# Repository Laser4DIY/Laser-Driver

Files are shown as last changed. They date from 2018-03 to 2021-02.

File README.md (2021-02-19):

# LASER4DIY Laser Diode Driver

Constant current power supply for laser diode to be used for the Laser4DIY project, see http://www.laser4diy.org/

Note: we are currently developing a new improved version of the laser diode driver, see https://github.com/Laser4DIY/Laser-Driver-v2

Copyright FabLab München e.V.  2021.

This source describes Open Hardware and is licensed under the CERN-OHL-P v2

You may redistribute and modify this documentation and make products using it 
under the terms of the CERN-OHL-P v2 (https:/cern.ch/cern-ohl).
This documentation is distributed WITHOUT ANY EXPRESS OR IMPLIED WARRANTY, 
INCLUDING OF MERCHANTABILITY, SATISFACTORY QUALITY AND FITNESS FOR A  PARTICULAR 
PURPOSE. Please see the CERN-OHL-P v2 for applicable conditions

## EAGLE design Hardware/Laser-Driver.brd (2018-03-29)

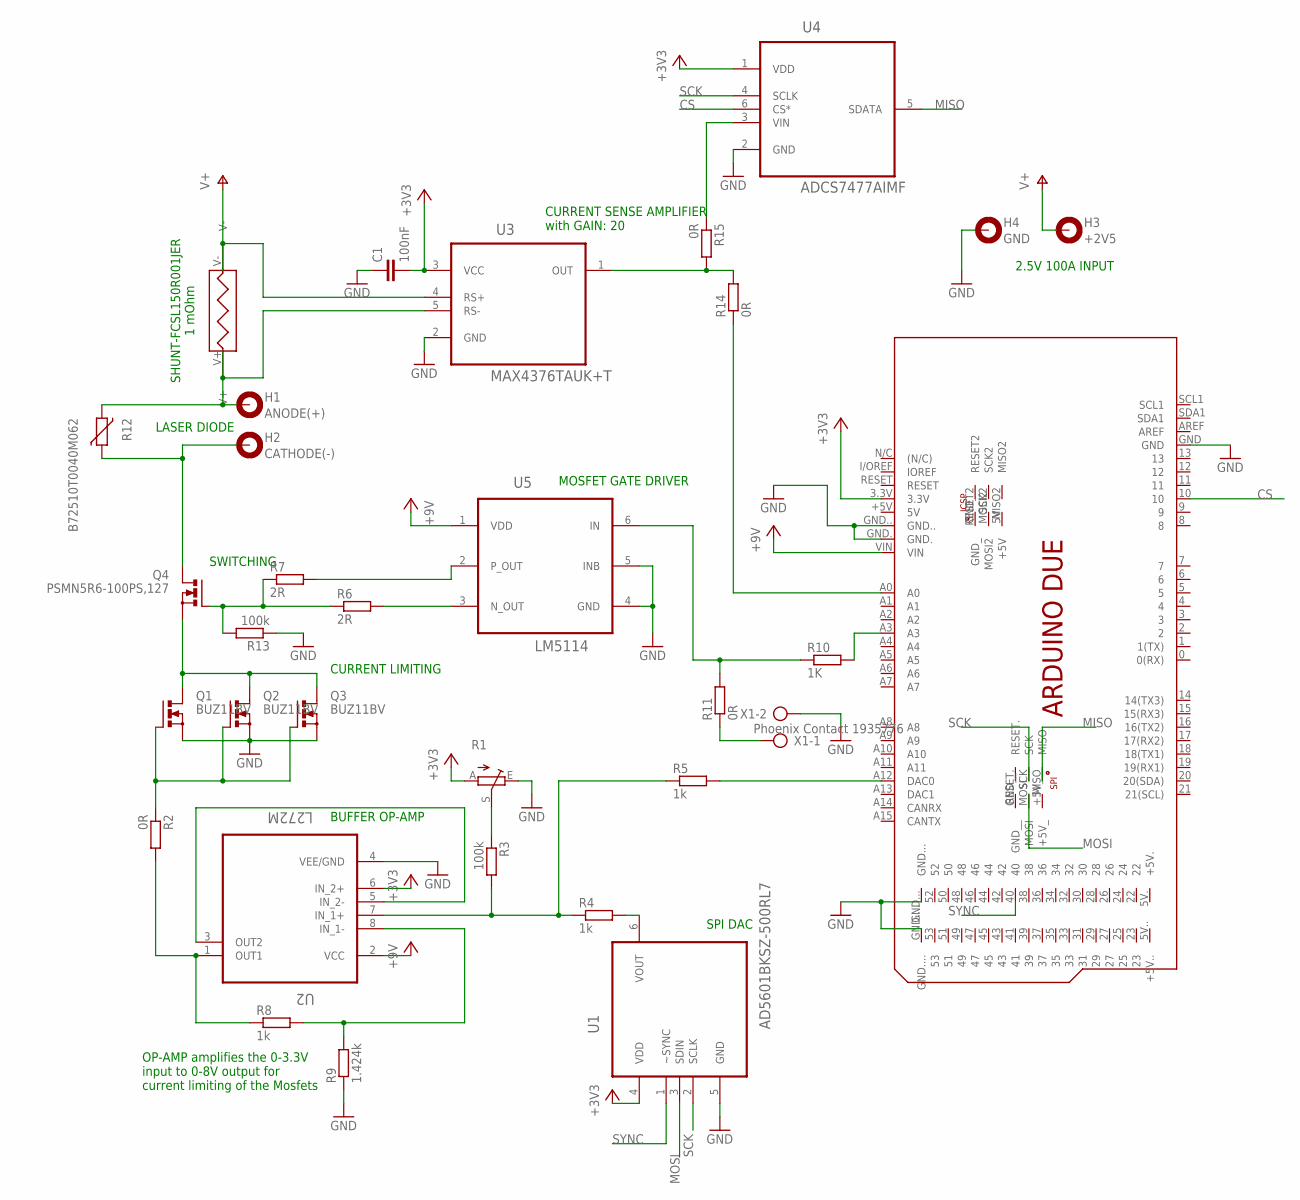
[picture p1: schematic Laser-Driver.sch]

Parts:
C1: 100nF; C0805
H1: ANODE(+); 3,2-PAD
H2: CATHODE(-); 3,2-PAD
H3: +2V5; 3,2-PAD
H4: GND; 3,2-PAD
PCB1: ARDUINO_DUE_SHIELD_SPI
Q1, Q2, Q3: BUZ11BV; TO220BV
Q4: PSMN5R6-100PS,127; TO220BV
R1: TRIM_EU-B64W; B64W
R2, R11, R14, R15: 0R; R0805
R3, R13: 100k; R0805
R4, R5, R8: 1k; R0805
R6, R7: 2R; R0805
R9: 1.424k; R0805
R10: 1K; R0805
R12: B72510T0040M062; CT/CN0805
U1: AD5601BKSZ-500RL7; SOT65P210X110-6N
U2: L272M; DIP254P762X508-8
U3: MAX4376TAUK+T; SOT95P280X145-5N
U4: ADCS7477AIMF; SOT95P280X145-6N
U5: LM5114; SOT95P280X145-6N
U$1: SHUNT-FCSL150R001-NOKELVIN
X1: Phoenix Contact 1935776; AK500/2

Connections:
+2V5: H3.B3,2, U3.4 (RS+), U$1.V-
+3V3: C1.2, PCB1.3.3V, R1.A, U1.4 (VDD), U2.6 (IN_2+), U3.3 (VCC), U4.1 (VDD)
+9V: PCB1.VIN, U2.2 (VCC), U5.1 (VDD)
CS: PCB1.10, U4.6 (CS*)
GND: C1.1, H4.B3,2, PCB1.GND, PCB1.GND., PCB1.GND.., PCB1.GND..., PCB1.GND...., Q1.S, Q2.S, Q3.S, R1.E, R9.1, R13.1, U1.5 (GND), U2.4 (VEE/GND), U3.2 (GND), U4.2 (GND), U5.4 (GND), U5.5 (INB), X1.2
MISO: PCB1.MISO, U4.5 (SDATA)
MOSI: PCB1.MOSI, U1.3 (SDIN)
unnamed: R7.2, U5.2 (P_OUT)
unnamed: H1.B3,2, R12.2, U3.5 (RS-), U$1.V+
unnamed: Q1.D, Q2.D, Q3.D, Q4.S
unnamed: R6.2, U5.3 (N_OUT)
unnamed: R2.2, R8.1, U2.1 (OUT1)
unnamed: Q1.G, Q2.G, Q3.G, R2.1
unnamed: U2.3 (OUT2), U2.5 (IN_2-)
unnamed: R3.2, R4.1, R5.1, U2.7 (IN_1+)
unnamed: R1.S, R3.1
unnamed: R4.2, U1.6 (VOUT)
unnamed: PCB1.A12 (DAC0), R5.2
unnamed: PCB1.A0, R14.1
unnamed: R8.2, R9.2, U2.8 (IN_1-)
unnamed: R10.1, R11.2, U5.6 (IN)
unnamed: PCB1.A3, R10.2
unnamed: R11.1, X1.1
unnamed: Q4.G, R6.1, R7.1, R13.2
unnamed: R14.2, R15.2, U3.1 (OUT)
unnamed: H2.B3,2, Q4.D, R12.1
unnamed: R15.1, U4.3 (VIN)
SCK: PCB1.SCK, U1.2 (SCLK), U4.4 (SCLK)
SYNC: PCB1.40, U1.1 (~SYNC)

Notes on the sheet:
SHUNT-FCSL150R001JER 1 mOhm
CURRENT SENSE AMPLIFIER with GAIN: 20
MOSFET GATE DRIVER
BUFFER OP-AMP
SPI DAC
LASER DIODE
2.5V 100A INPUT
OP-AMP amplifies the 0-3.3V input to 0-8V output for current limiting of the Mosfets
SWITCHING
CURRENT LIMITING

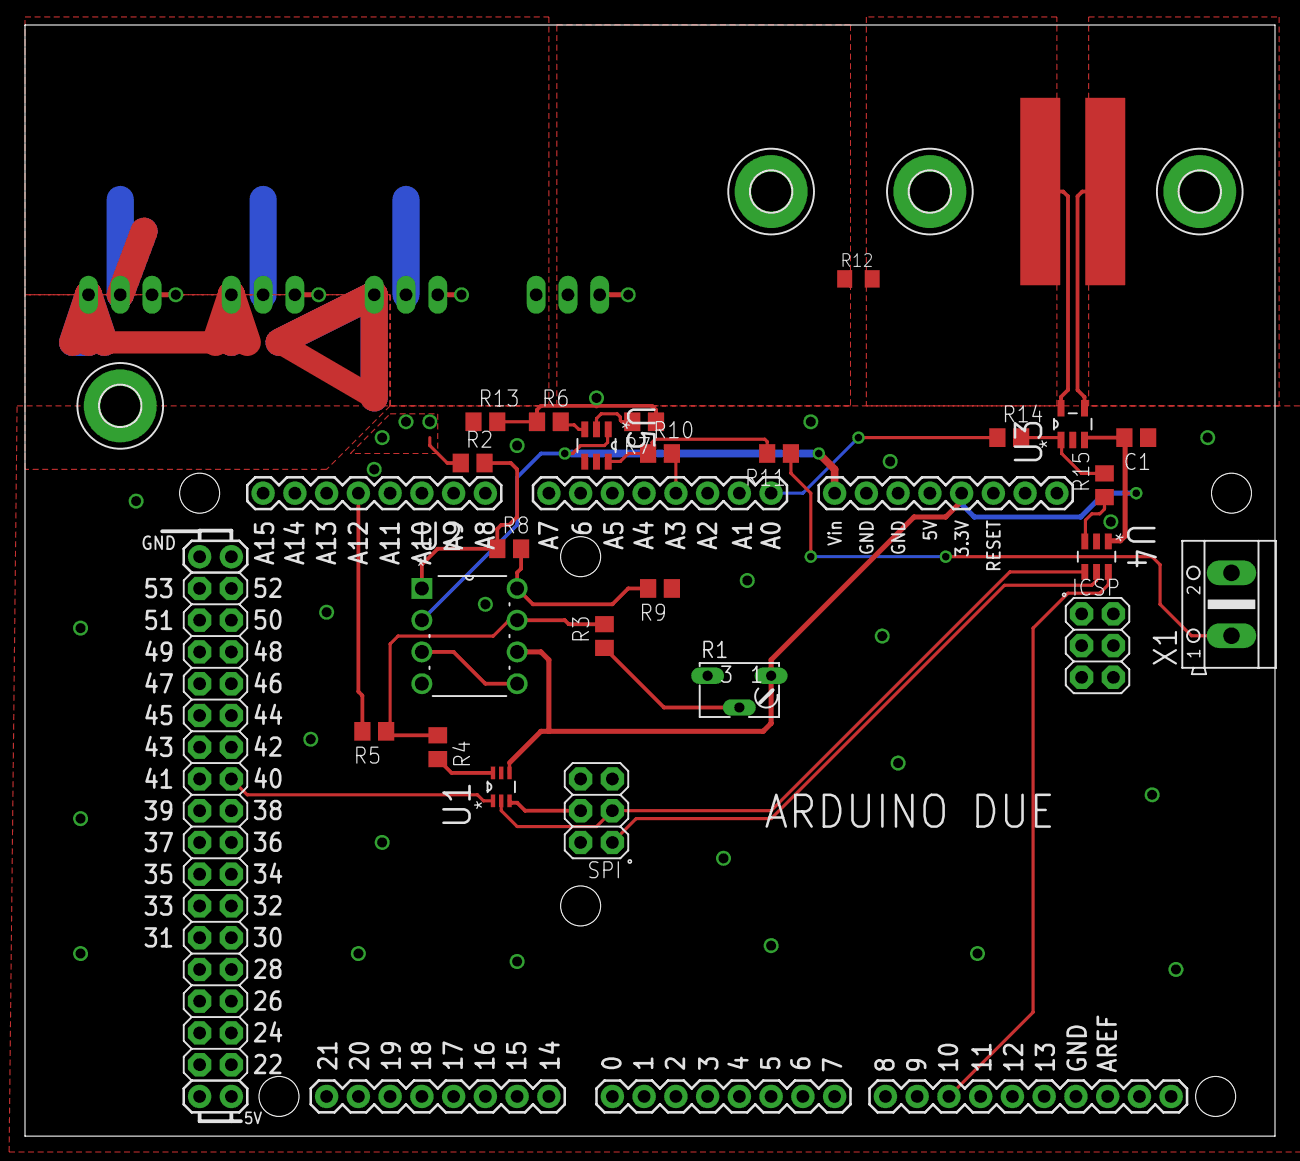
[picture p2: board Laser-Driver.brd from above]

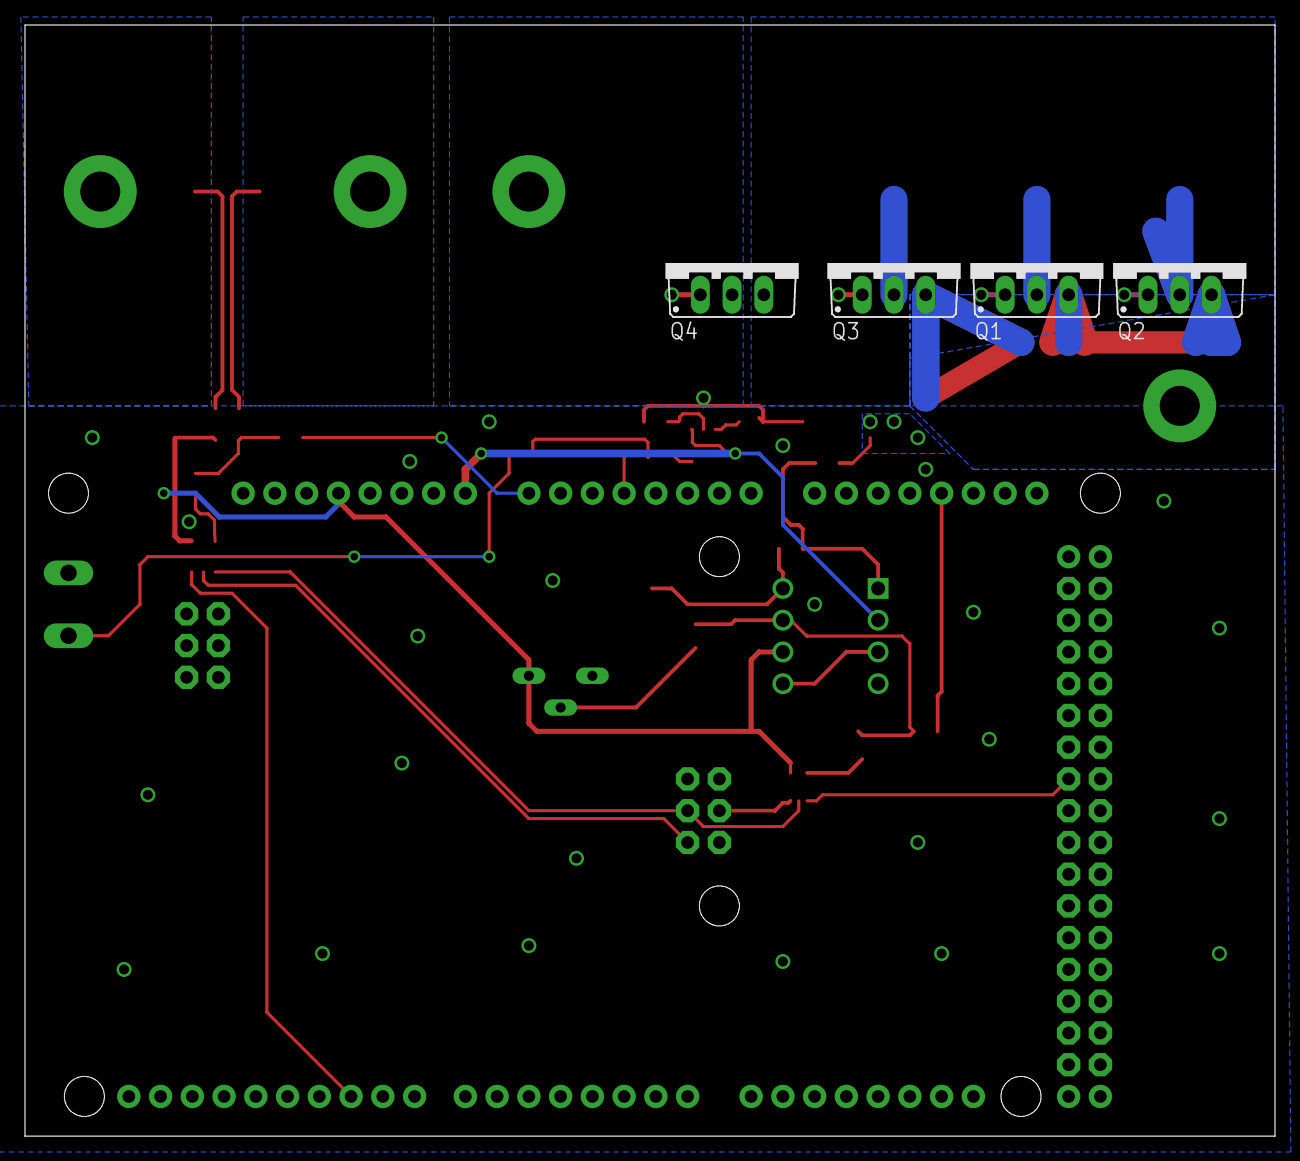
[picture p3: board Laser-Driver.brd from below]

Board: 2 copper layers, 100.0 x 88.9 mm, 32 parts (4 on the bottom side), 29 nets.

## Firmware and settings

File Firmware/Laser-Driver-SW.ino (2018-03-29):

#define SWITCH_PIN A3
#define CURRENT_PIN A0
#define LED_PIN 13
//use a toggle switch (SPDT) between PIN 7 (A), 6 (COMMON), 5 (B) to choose between PULSE and CW mode
#define A_PIN 7
#define COMMON_PIN 6
#define B_PIN 5

boolean switchState = 1 ;
long lastTime = 0;

void setup() {
  Serial.begin(115200);
  analogReadResolution(12);
  //define in- and outputs
  pinMode(CURRENT_PIN, INPUT);
  pinMode(SWITCH_PIN, OUTPUT);
  digitalWrite(SWITCH_PIN, HIGH);
  pinMode(LED_PIN, OUTPUT);
  //toggle switch for mode selection  
  pinMode(A_PIN, INPUT_PULLUP);
  pinMode(COMMON_PIN, OUTPUT);
  digitalWrite(COMMON_PIN, LOW);
  pinMode(B_PIN, INPUT_PULLUP);
  lastTime=millis();
}

void loop() {
  // read the input on the current measurement pin:
  int sensorValue = analogReadN(CURRENT_PIN,30);
  float outputValue = convert2Ampere(sensorValue);
  //output the measured current via serial
  Serial.print(sensorValue); Serial.print(": "); Serial.println(outputValue);
  delay(200);
  //send out pulse every 3sec if switch is on pulse mode
  if(millis()-lastTime > 3000) {
    digitalWrite(SWITCH_PIN, HIGH);
    digitalWrite(13, HIGH);
    delayMicroseconds(50);
    if(digitalRead(7)==LOW) {
      digitalWrite(SWITCH_PIN, LOW);
      digitalWrite(13, LOW);
    }
    //serial output for debugging the pulses
    Serial.print("* "); Serial.println(switchState);
    switchState=!switchState;
    lastTime=millis();
  }
}

float convert2Ampere(int rawInput) {
  int temp=rawInput+43; //offset evaluated experimentally
  if(temp<0) temp=0;
  float conversionFactor = 0.0424; //evaluated experimentally
  //float conversionFactor = 0.040283203125;  // theoretical: (100A / 2 Volt)*(3.3 Volt /4096)
  return conversionFactor*rawInput;  
}

int analogReadN(int pinNumber, int iterations) {
  int result=0;
  for(int i=0; i<iterations; i++) {
    result = result + analogRead(pinNumber);
  }
  return result/iterations;
}

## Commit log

2018-03-29 Revert "initial release"
    This reverts commit 8b9e5df8129df3e1c51870e52f897e7ae3e3be9e.
    [Laser-Driver-SW.ino]
2018-03-29 initial commit
    This is a testversion
    [Laser-Driver.brd, Laser-Driver.sch]
